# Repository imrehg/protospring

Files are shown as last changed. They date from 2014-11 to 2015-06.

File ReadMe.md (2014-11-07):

# ProtoSpring

Prototyping board for the [VIA VAB-600 Springboard][vab600]. Schematics
and PCB done in KiCad.

## Information

For more information on this hardware, you can contact at <gergely@imreh.net>.

### Bill of Materials

| Mouser # | Mfr. # | Manufacturer | Desc. |
|---|---|---|---|
| 576-1206L110THYR | 1206L110THYR | Littelfuse | Resettable Fuses - PPTC PTC 8V 1206 1.1A POLYFUSE SMD THIN |
| 647-F931A106KAA | F931A106KAA | AVX | Tantalum Capacitors - Solid SMD 10uF 10V 10% |
| 581-060316C104K | 0603YC104KAT2A | AVX | Multilayer Ceramic Capacitors MLCC - SMD/SMT 16volts 0.1uF 10% X7R |
| 71-CRCW0603-390-E3 | CRCW0603390RFKEA  | Vishay | Thick Film Resistors - SMD 1/10watt 390ohms 1% |
| 720-LBQ39GL2N2351  | LB Q39G-L2N2-35-1 | Osram Opto Semiconductor | Standard LEDs - SMD Blue |
| 517-950408-5002-AR | 950408-5002-AR | 3M | Headers & Wire Housings 8P BDMNT SKT 2R STRT PTH 10U AU |
| 517-950406-5002-AR | 950406-5002-AR | 3M | Headers & Wire Housings 6P BDMNT SKT 2R STRT PTH 10U AU |
| 517-950414-5002-AR | 950414-5002-AR | 3M | Headers & Wire Housings 14P BDMNT SKT 2R STRT PTH 10U AU |

## Bugs, modifications

If you find any bugs on the board or want to suggest improvements, I'm always
happy to hear. Either submit an Issue on Github, or send me an email.

## License

This hardware is provided under the [CERN Open Hardware License 1.2][ohl].
The license text is included in `cern_ohl_v_1_2.txt` of this package.

[vab600]: http://www.viaspringboard.com "VIA Springboard site"
[ohl]: http://www.ohwr.org/documents/294 "CERN OHL VERSION 1.2"

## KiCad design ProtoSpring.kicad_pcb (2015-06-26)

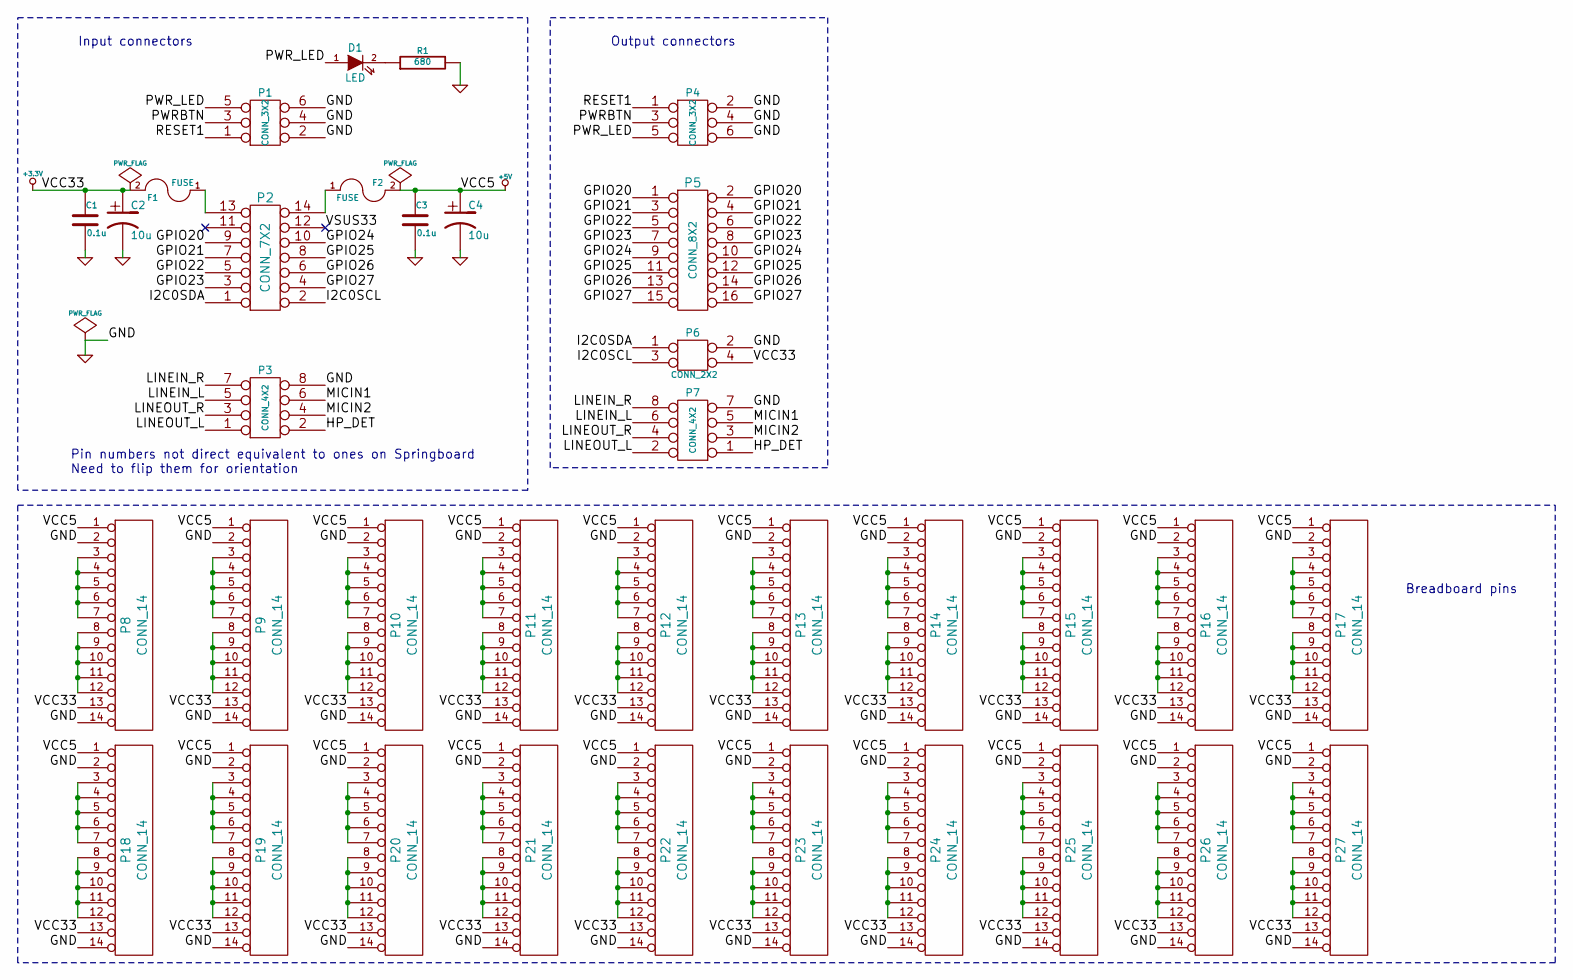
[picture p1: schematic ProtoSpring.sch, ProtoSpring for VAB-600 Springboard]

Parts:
C1, C3: 0.1u; SM0603; PartNumber 0603YC104KAT2A
C2, C4: 10u; SM1206; PartNumber F931A106KAA
D1: LED; SM0603; PartNumber LB Q39G-L2N2-35-1
F1, F2: FUSE; SMD1206; PartNumber 1206L110THYR
P1: CONN_3X2; Part# 950406-5002-AR
P2: CONN_7X2; Part# 950414-5002-AR
P3: CONN_4X2; Part# 950408-5002-AR
P4: CONN_3X2
P5: CONN_8X2
P6: CONN_2X2
P7: CONN_4X2
P8, P9, P10, P11, P12, P13, P14, P15, P16, P17, P18, P19, P20, P21, P22, P23, P24, P25, P26, P27: CONN_14
R1: 680; SM0603; Part# CRCW0603680RFKEA

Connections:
+3.3V: C1.1, C2.1, F1.2, P6.4, P8.13, P9.13, P10.13, P11.13, P12.13, P13.13, P14.13, P15.13, P16.13, P17.13, P18.13, P19.13, P20.13, P21.13, P22.13, P23.13, P24.13, P25.13, P26.13, P27.13
+5V: C3.1, C4.1, F2.2, P8.1, P9.1, P10.1, P11.1, P12.1, P13.1, P14.1, P15.1, P16.1, P17.1, P18.1, P19.1, P20.1, P21.1, P22.1, P23.1, P24.1, P25.1, P26.1, P27.1
/GPIO20: P2.9, P5.1, P5.2
/GPIO21: P2.7, P5.3, P5.4
/GPIO22: P2.5, P5.5, P5.6
/GPIO23: P2.3, P5.7, P5.8
/GPIO24: P2.10, P5.9, P5.10
/GPIO25: P2.8, P5.11, P5.12
/GPIO26: P2.6, P5.13, P5.14
/GPIO27: P2.4, P5.15, P5.16
/HP_DET: P3.2, P7.1
/I2C0SCL: P2.2, P6.3
/I2C0SDA: P2.1, P6.1
/LINEIN_L: P3.5, P7.6
/LINEIN_R: P3.7, P7.8
/LINEOUT_L: P3.1, P7.2
/LINEOUT_R: P3.3, P7.4
/MICIN1: P3.6, P7.5
/MICIN2: P3.4, P7.3
/PWRBTN: P1.3, P4.3
/PWR_LED: D1.1 (A), P1.5, P4.5
/RESET1: P1.1, P4.1
GND: C1.2, C2.2, C3.2, C4.2, P1.2, P1.4, P1.6, P3.8, P4.2, P4.4, P4.6, P6.2, P7.7, P8.2, P8.14, P9.2, P9.14, P10.2, P10.14, P11.2, P11.14, P12.2, P12.14, P13.2, P13.14, P14.2, P14.14, P15.2, P15.14, P16.2, P16.14, P17.2, P17.14, P18.2, P18.14, P19.2, P19.14, P20.2, P20.14, P21.2, P21.14, P22.2, P22.14, P23.2, P23.14, P24.2, P24.14, P25.2, P25.14, P26.2, P26.14, P27.2, P27.14, R1.2
unnamed: P18.8, P18.9, P18.10, P18.11, P18.12
unnamed: P19.3, P19.4, P19.5, P19.6, P19.7
unnamed: P19.8, P19.9, P19.10, P19.11, P19.12
unnamed: P18.3, P18.4, P18.5, P18.6, P18.7
unnamed: P20.8, P20.9, P20.10, P20.11, P20.12
unnamed: P20.3, P20.4, P20.5, P20.6, P20.7
unnamed: P15.8, P15.9, P15.10, P15.11, P15.12
unnamed: P14.8, P14.9, P14.10, P14.11, P14.12
unnamed: P15.3, P15.4, P15.5, P15.6, P15.7
unnamed: P17.3, P17.4, P17.5, P17.6, P17.7
unnamed: P17.8, P17.9, P17.10, P17.11, P17.12
unnamed: P16.3, P16.4, P16.5, P16.6, P16.7
unnamed: P16.8, P16.9, P16.10, P16.11, P16.12
unnamed: P25.8, P25.9, P25.10, P25.11, P25.12
unnamed: P25.3, P25.4, P25.5, P25.6, P25.7
unnamed: P27.3, P27.4, P27.5, P27.6, P27.7
unnamed: P27.8, P27.9, P27.10, P27.11, P27.12
unnamed: P26.3, P26.4, P26.5, P26.6, P26.7
unnamed: P26.8, P26.9, P26.10, P26.11, P26.12
unnamed: P22.3, P22.4, P22.5, P22.6, P22.7
unnamed: P22.8, P22.9, P22.10, P22.11, P22.12
unnamed: P21.3, P21.4, P21.5, P21.6, P21.7
unnamed: P21.8, P21.9, P21.10, P21.11, P21.12
unnamed: P24.3, P24.4, P24.5, P24.6, P24.7
unnamed: P24.8, P24.9, P24.10, P24.11, P24.12
unnamed: P23.3, P23.4, P23.5, P23.6, P23.7
unnamed: P23.8, P23.9, P23.10, P23.11, P23.12
unnamed: F2.1, P2.14
unnamed: F1.1, P2.13
unnamed: D1.2 (K), R1.1
unnamed: P12.3, P12.4, P12.5, P12.6, P12.7
unnamed: P12.8, P12.9, P12.10, P12.11, P12.12
unnamed: P11.3, P11.4, P11.5, P11.6, P11.7
unnamed: P11.8, P11.9, P11.10, P11.11, P11.12
unnamed: P14.3, P14.4, P14.5, P14.6, P14.7
unnamed: P13.3, P13.4, P13.5, P13.6, P13.7
unnamed: P13.8, P13.9, P13.10, P13.11, P13.12
unnamed: P8.8, P8.9, P8.10, P8.11, P8.12
unnamed: P9.3, P9.4, P9.5, P9.6, P9.7
unnamed: P9.8, P9.9, P9.10, P9.11, P9.12
unnamed: P8.3, P8.4, P8.5, P8.6, P8.7
unnamed: P10.3, P10.4, P10.5, P10.6, P10.7
unnamed: P10.8, P10.9, P10.10, P10.11, P10.12

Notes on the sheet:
Input connectors
Output connectors
Breadboard pins
Pin numbers not direct equivalent to ones on Springboard Need to flip them for orientation

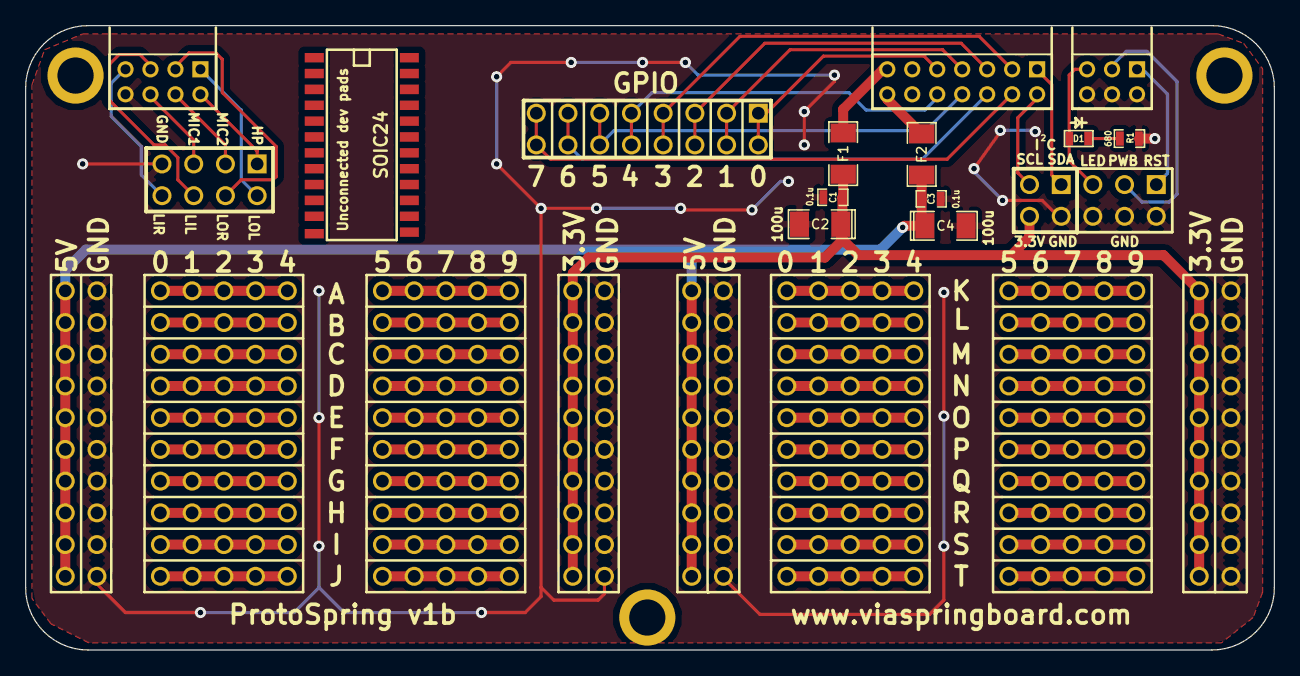
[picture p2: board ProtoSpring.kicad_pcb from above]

Board: 2 copper layers, 100.0 x 50.0 mm, 39 parts (0 on the bottom side), 66 nets.

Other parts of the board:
MOUNT_HOLE_1, MOUNT_HOLE_2, MOUNT_HOLE_3: Val**; MOUNTING_HOLE_M25
SOIC24: VAL**; SOIC24

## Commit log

2014-11-06 updated output
    [ProtoSpring.kicad_pcb, ProtoSpring.sch]
2014-11-07 add BOM
2014-11-09 update schematics and pcb with some lessons learned
    Brief changelog:
    * add manufacturers and part numbers for recommended parts
    * change current limiting resistor for LED to fit its current requirements
    * update PCB with new resistor value
    [ProtoSpring.kicad_pcb, ProtoSpring.sch]
2014-11-09 update BOM
2014-11-14 adjusting the paths for the Audio headers
    [ProtoSpring.kicad_pcb]
2014-11-14 add missing path back for vias
    [ProtoSpring.kicad_pcb]
2014-11-14 add BOM table
    [BOM.csv]
2014-12-05 bugfix: i2c lines labeling
    The SDA and SCL lines were mixed up on the silkscreen. Fix their
    labels and update version number on the board to reflect this change.
    [ProtoSpring.kicad_pcb]
2015-06-26 latest changes
    [ProtoSpring.kicad_pcb, ProtoSpring.sch]

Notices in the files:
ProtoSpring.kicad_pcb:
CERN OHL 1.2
